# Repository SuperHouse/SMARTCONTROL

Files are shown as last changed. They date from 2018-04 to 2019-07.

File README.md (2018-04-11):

Home Automation Smart Switch Controller
=======================================
Copyright 2017-2018 SuperHouse Automation Pty Ltd <www.superhouse.tv>  

Control board for home automation switches. Mounts on the back of an
illuminated button breakout, and connects to a central controller via
wires or WiFi.

Features:

 * ESP8266 with WiFi
 * RJ45 breakout to allow connecting using Cat-5 cable

More information is available at:

  http://www.superhouse.tv/smartcontrol

INSTALLATION
------------
The design is saved as an EAGLE project. EAGLE PCB design software is
available from www.cadsoftusa.com free for non-commercial use. To use
this project download it and place the directory containing these files
into the "eagle" directory on your computer. Then open EAGLE and
navigate to the project.

DISTRIBUTION
------------
The specific terms of distribution of this project are governed by the
license referenced below.

LICENSE
-------
Licensed under the TAPR Open Hardware License (www.tapr.org/OHL).
The "license" folder within this repository also contains a copy of
this license in plain text format.

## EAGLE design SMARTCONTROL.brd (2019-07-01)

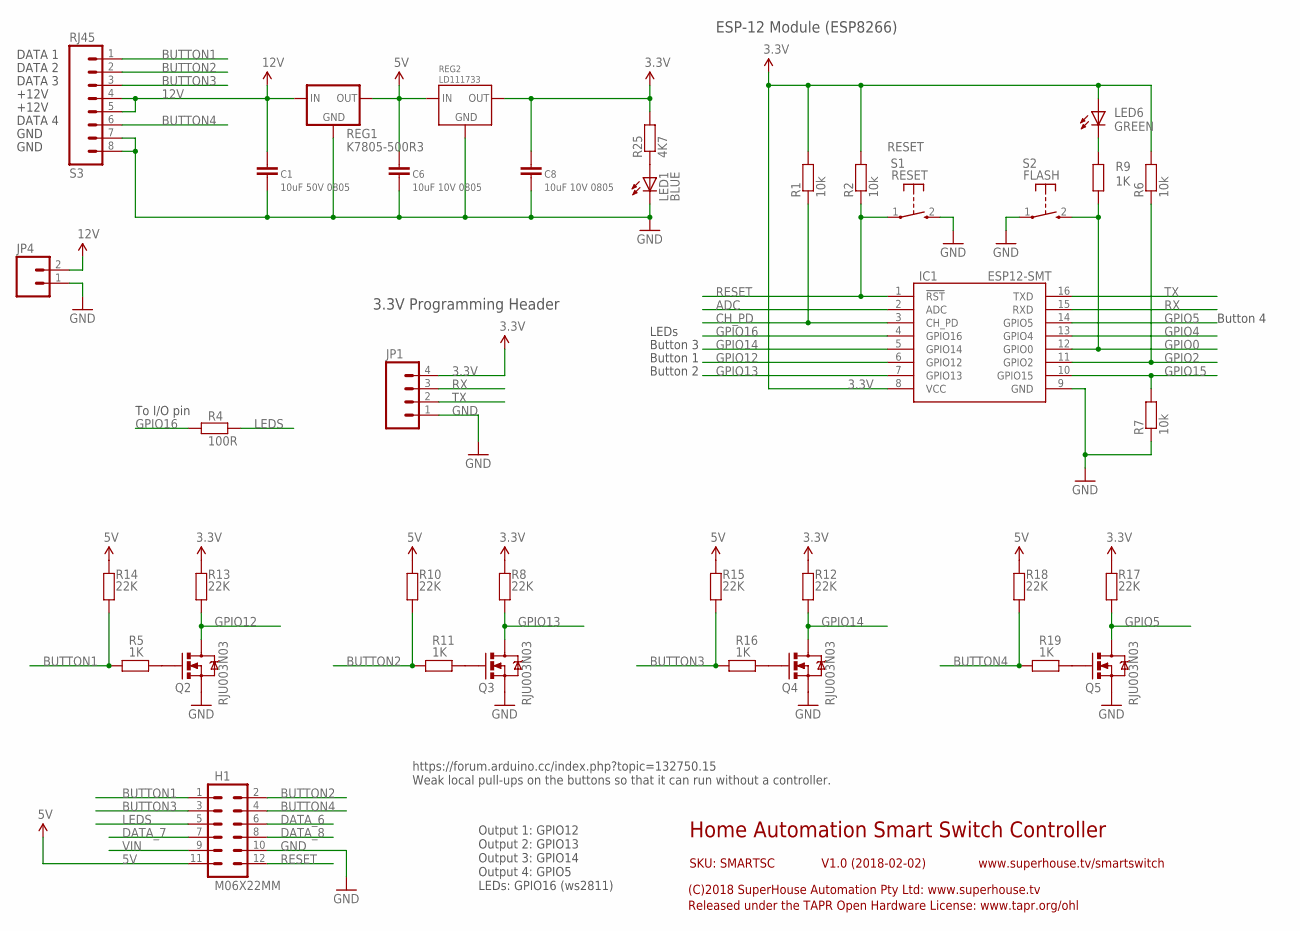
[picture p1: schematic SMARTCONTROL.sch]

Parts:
C1: 10uF 50V 0805; C0805
C6, C8: 10uF 10V 0805; C0805
H1: M06X22MM; 2X6-2MM
IC1: ESP12-SMT; ESP12
JP1: M04PTH; 1X04
JP4: M023.5MM; SCREWTERMINAL-3.5MM-2
LED1: BLUE; LED-0603
LED6: GREEN; LED-0603
Q2, Q3, Q4, Q5: RJU003N03; SOT32-3
R1, R2, R6, R7: 10k; R0603
R4: 100R; R0603
R5, R9, R11, R16, R19: 1K; R0603
R8, R10, R12, R13, R14, R15, R17, R18: 22K; R0603
R25: 4K7; R0603
REG1: K7805-500R3; K78XX-500R3
REG2: LD111733; SOT-223
S1: RESET; TACTILE_SMD_3X4X2
S2: FLASH; TACTILE_SMD_3X4X2
S3: RJ45

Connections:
3.3V: C8.1, IC1.8 (VCC), JP1.4, LED6.A, R1.2, R2.2, R6.2, R8.2, R12.2, R13.2, R17.2, R25.2, REG2.2 (OUT), REG2.4 (OUT)
5V: C6.1, H1.11, R10.2, R14.2, R15.2, R18.2, REG1.3 (OUT), REG2.3 (IN)
12V: C1.1, JP4.2, REG1.1 (IN), S3.4, S3.5
ADC: IC1.2 (ADC)
BUTTON1: H1.1, R5.2, R14.1, S3.1
BUTTON2: H1.2, R10.1, R11.2, S3.2
BUTTON3: H1.3, R15.1, R16.2, S3.3
BUTTON4: H1.4, R18.1, R19.2, S3.6
CH_PD: IC1.3 (CH_PD), R1.1
DATA_6: H1.6
DATA_7: H1.7
DATA_8: H1.8
GND: C1.2, C6.2, C8.2, H1.10, IC1.9 (GND), JP1.1, JP4.1, LED1.C, Q2.2 (S), Q3.2 (S), Q4.2 (S), Q5.2 (S), R7.1, REG1.2 (GND), REG2.1 (GND), S1.2 (S), S2.1, S3.7, S3.8
GPIO0: IC1.12 (GPIO0), R9.2, S2.2 (S)
GPIO2: IC1.11 (GPIO2), R6.1
GPIO4: IC1.13 (GPIO4)
GPIO5: IC1.14 (GPIO5), Q5.3 (D), R17.1
GPIO12: IC1.6 (GPIO12), Q2.3 (D), R13.1
GPIO13: IC1.7 (GPIO13), Q3.3 (D), R8.1
GPIO14: IC1.5 (GPIO14), Q4.3 (D), R12.1
GPIO15: IC1.10 (GPIO15), R7.2
GPIO16: IC1.4 (GPIO16), R4.2
LEDS: H1.5, R4.1
unnamed: Q2.1 (G), R5.1
unnamed: Q3.1 (G), R11.1
unnamed: Q4.1 (G), R16.1
unnamed: Q5.1 (G), R19.1
unnamed: LED1.A, R25.1
unnamed: LED6.C, R9.1
RESET: H1.12, IC1.1 (!RST), R2.1, S1.1
RX: IC1.15 (RXD), JP1.3
TX: IC1.16 (TXD), JP1.2
VIN: H1.9

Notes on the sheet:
Home Automation Smart Switch Controller
V1.0 (2018-02-02)
SKU: SMARTSC
(C)2018 SuperHouse Automation Pty Ltd: www.superhouse.tv
Released under the TAPR Open Hardware License: www.tapr.org/ohl
www.superhouse.tv/smartswitch
https://forum.arduino.cc/index.php?topic=132750.15 Weak local pull-ups on the buttons so that it can run without a controller.
ESP-12 Module (ESP8266)
Output 1: GPIO12 Output 2: GPIO13 Output 3: GPIO14 Output 4: GPIO5 LEDs: GPIO16 (ws2811)
3.3V Programming Header
DATA 1
DATA 2
DATA 3
DATA 4
+12V
GND
To I/O pin
Button 1
Button 2
Button 3
Button 4
LEDs

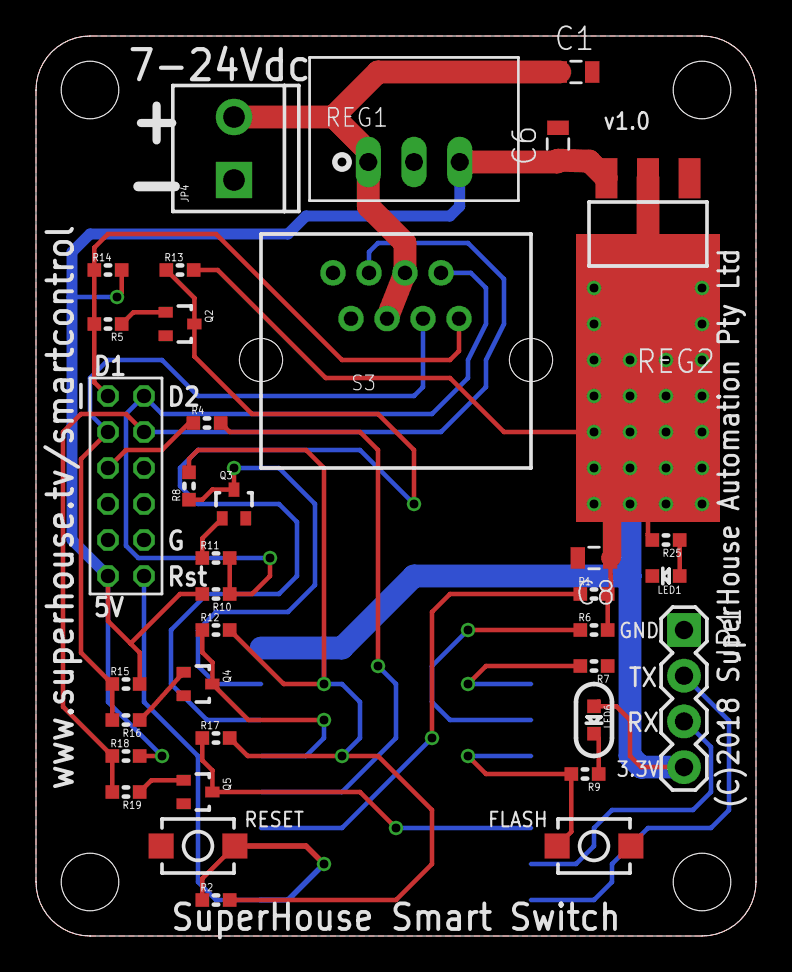
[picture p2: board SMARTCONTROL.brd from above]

Board: 2 copper layers, 40.0 x 50.0 mm, 37 parts (1 on the bottom side), 27 nets.

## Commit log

2018-04-11 Re-import of project developed over the last 9 months
    [SMARTCONTROL.brd, SMARTCONTROL.sch]
2018-04-11 Fixed ESP-12 footprint (swapped D4/5)
    [SMARTCONTROL.brd, SMARTCONTROL.sch]
2019-07-01 Replaced most parts using SuperHouse library to add 3D models
    [SMARTCONTROL.brd, SMARTCONTROL.sch]
